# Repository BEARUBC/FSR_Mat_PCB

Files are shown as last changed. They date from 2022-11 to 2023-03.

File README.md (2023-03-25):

# FSR Matrix Printed Circuit Board

**As of 2023-03-24, this README is outdated. Documentation for Tiaan's FSR is in progress. 

<p align="center">
These are the CAD files for the FSR printed circuit boards (PCB) using through-hole only components. This board is used for controlling a force sensitive resistor matrix, reading analog values from each cell.  
</p>

## 📖 Description

This design is based off of Sensitronics' MatrixArray products which are comprised of a multitude of force sensing resistor elements arranged in a grid.
Providing n-input multitouch + force sensing capabilities, MatrixArrays are the basis for musical instruments, PC input devices, and other innovative designs.
If you have measured single-element FSRs by looking at the voltage across a divider, we're doing the same thing here.

But in this case, we're choosing the point to measure by powering a single drive column, enabling one mux channel so that the ADC sees a single row.
In the next section, the Arduino code demonstrates a scan pattern to read all $\approx$ 160 elements in sequence.

### 🚨 Dependencies

* Software
  * KiCAD v6
* Hardware
  * ThruMode MatrixArray
  * Arduino Uno (or other)
  * 74HC595 Shift Register (x2)
  * 74HC4051 Analog Multiplexer (x2)
  * 20k resistor (x1)
  * Solderless Breadboard & Jumper Wire

### 💻 Installing

#### 🕹️ Software

Use a web browser to navigate to www.kicad.org the KiCad EDA website. Click the DOWNLOAD button on the KiCad home page. On the download page that opens, click the Windows button. Under Stable Release, click either Windows 64-bit or Windows 32-bit, depending on if you are going to install KiCad on a 32-bit or 64-bit version of the Windows operating system. Save the KiCad installation file. It may take a while to download, depending on your internet speed.

1. Click the Open button under File > Open (`Ctrl + O`) and navigate to this repository
2. Select the `force_sens_resistor.kicad_pro` file
3. Double click the `*.sch` file and begin to edit the board

#### 🤖 Hardware

Arrange the hardware connections folling this schematic:

<p align="center">
  
</p>

### ▶️ Executing program

Now that the hardware's connected, it's time to write some code.

To read a single intersection, or "cell", of the MatrixArray, we need to perform the following sequence:

* Drive the cell's row with +5V
* Enable the cell's column (multiplexer channel)
* Take an ADC reading on pin A0
* Output the reading via serial port

Simple enough, so from here, we will write a scan pattern to efficiently drive and read each cell of the Matrix. Recalling that we're calling shift register drive pins "rows" and multiplexed read pins "columns" in this example, we'll enable each column in order, and while each column is active, we'll drive each row high and take a reading.

```cpp
// Constant definitions
...

void setup() {
  Serial.begin(BAUD_RATE);

  pinMode(PIN_ADC_INPUT, INPUT);
  pinMode(PIN_SHIFT_REGISTER_DATA, OUTPUT);
  pinMode(PIN_SHIFT_REGISTER_CLOCK, OUTPUT);
  pinMode(PIN_MUX_CHANNEL_0, OUTPUT);
  pinMode(PIN_MUX_CHANNEL_1, OUTPUT);
  pinMode(PIN_MUX_CHANNEL_2, OUTPUT);
  pinMode(PIN_MUX_INHIBIT_0, OUTPUT);
  pinMode(PIN_MUX_INHIBIT_1, OUTPUT);
}
void loop() {
  for(int i = 0; i < ROW_COUNT; i ++) {
    setRow(i);
    shiftColumn(true);
    shiftColumn(false);                         //with SR clks tied, latched outputs are one clock behind

    for(int j = 0; j < COLUMN_COUNT; j ++) {
      int raw_reading = analogRead(PIN_ADC_INPUT);
      byte send_reading = (byte) (lowByte(raw_reading >> 2));
      shiftColumn(false);
      printFixed(send_reading);
      Serial.print(" ");
    }
    Serial.println();
  }
  Serial.println();
  delay(200);
}

...

// Function implementations for `setRow`, `shiftCoumn`, and `printFixed`

```

## 🧔🏽‍♂️Authors

Contributors names and contact info

Tiaan Boshoff
Kyle Kochi
Tiffany Prayitino
Umar Ali  

## 🧾 Version History

* 1.0
    * Initial Release following Sensitronics' MatrixArray tutorial

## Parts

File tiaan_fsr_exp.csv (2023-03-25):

Id | Designator | Footprint | Quantity | Designation | Supplier and ref
1 | C4,C2,C3,C1 | CP_Radial_D4.0mm_P2.00mm | 4 | 0.1uF
2 | J3,J5 | PinHeader_1x02_P2.54mm_Vertical | 2 | Conn_01x02
3 | R1 | R_Axial_DIN0207_L6.3mm_D2.5mm_P10.16mm_Horizontal | 1 | 20k
4 | J2 | JST_XH_S3B-XH-A-1_1x03_P2.50mm_Horizontal | 1 | Conn_01x03
5 | H1,H3,H4,H2 | MountingHole_2.7mm_M2.5_DIN965_Pad | 4 | MountingHole
6 | J4 | IDC-Header_2x17_P2.54mm_Vertical | 1 | Conn_02x17_Odd_Even
7 | MUX1,MUX2 | DIP-16_W7.62mm_Socket | 2 | 74HC4051
8 | SR2,SR1 | DIP-16_W7.62mm_Socket | 2 | 74HC595
9 | J1 | JST_XH_S6B-XH-A-1_1x06_P2.50mm_Horizontal | 1 | Conn_01x06

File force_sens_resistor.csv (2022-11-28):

Source: | C:\Users\umaru\Documents\cad\fsr\force_sens_resistor\force_sens_resistor.kicad_sch
Date: | 11/27/2022 8:21:04 PM
Tool: | Eeschema (6.0.6)
Generator: | C:\Program Files\KiCad\6.0\bin\scripting\plugins/bom_csv_grouped_by_value.py
Component Count: | 12
Individual Components:
Item | Qty | Reference(s) | Value | LibPart | Footprint | Datasheet
 |  | C1 | 0.1uF | Device:C_Polarized_Small_US | Capacitor_THT:CP_Axial_L10.0mm_D4.5mm_P15.00mm_Horizontal | ~
 |  | C2 | 0.1uF | Device:C_Polarized_Small_US | Capacitor_THT:CP_Axial_L10.0mm_D4.5mm_P15.00mm_Horizontal | ~
 |  | C3 | 0.1uF | Device:C_Polarized_Small_US | Capacitor_THT:CP_Axial_L10.0mm_D4.5mm_P15.00mm_Horizontal | ~
 |  | C4 | 0.1uF | Device:C_Polarized_Small_US | Capacitor_THT:CP_Axial_L10.0mm_D4.5mm_P15.00mm_Horizontal | ~
 |  | J1 | MCU_HEADER_PINS | Connector:Conn_01x09_Female | Connector_PinSocket_1.00mm:PinSocket_1x09_P1.00mm_Vertical | ~
 |  | J2 | DRIVE_COLS | Connector:Conn_01x16_Female | Connector_PinSocket_1.00mm:PinSocket_1x16_P1.00mm_Vertical | ~
 |  | J3 | READ_ROWS | Connector:Conn_01x10_Female | Connector_PinSocket_1.00mm:PinSocket_1x10_P1.00mm_Vertical | ~
 |  | R1 | 20k | Device:R_Small | Resistor_THT:R_Axial_DIN0204_L3.6mm_D1.6mm_P1.90mm_Vertical | ~
 |  | U1 | 74HCT595 | 74xx:74HCT595 | Package_DIP:DIP-16_W7.62mm_LongPads | https://assets.nexperia.com/documents/data-sheet/74HC_HCT595.pdf
 |  | U2 | 74HCT595 | 74xx:74HCT595 | Package_DIP:DIP-16_W7.62mm_LongPads | https://assets.nexperia.com/documents/data-sheet/74HC_HCT595.pdf
 |  | U3 | 4051 | 4xxx:4051 | Package_DIP:DIP-16_W10.16mm | http://www.intersil.com/content/dam/Intersil/documents/cd40/cd4051bms-52bms-53bms.pdf
 |  | U4 | 4051 | 4xxx:4051 | Package_DIP:DIP-16_W10.16mm | http://www.intersil.com/content/dam/Intersil/documents/cd40/cd4051bms-52bms-53bms.pdf
Collated Components:
Item | Qty | Reference(s) | Value | LibPart | Footprint | Datasheet
1 | 4 | C1, C2, C3, C4 | 0.1uF | Device:C_Polarized_Small_US | Capacitor_THT:CP_Axial_L10.0mm_D4.5mm_P15.00mm_Horizontal | ~
2 | 1 | J1 | MCU_HEADER_PINS | Connector:Conn_01x09_Female | Connector_PinSocket_1.00mm:PinSocket_1x09_P1.00mm_Vertical | ~
3 | 1 | J2 | DRIVE_COLS | Connector:Conn_01x16_Female | Connector_PinSocket_1.00mm:PinSocket_1x16_P1.00mm_Vertical | ~
4 | 1 | J3 | READ_ROWS | Connector:Conn_01x10_Female | Connector_PinSocket_1.00mm:PinSocket_1x10_P1.00mm_Vertical | ~
5 | 1 | R1 | 20k | Device:R_Small | Resistor_THT:R_Axial_DIN0204_L3.6mm_D1.6mm_P1.90mm_Vertical | ~
6 | 2 | U1, U2 | 74HCT595 | 74xx:74HCT595 | Package_DIP:DIP-16_W7.62mm_LongPads | https://assets.nexperia.com/documents/data-sheet/74HC_HCT595.pdf
7 | 2 | U3, U4 | 4051 | 4xxx:4051 | Package_DIP:DIP-16_W10.16mm | http://www.intersil.com/content/dam/Intersil/documents/cd40/cd4051bms-52bms-53bms.pdf

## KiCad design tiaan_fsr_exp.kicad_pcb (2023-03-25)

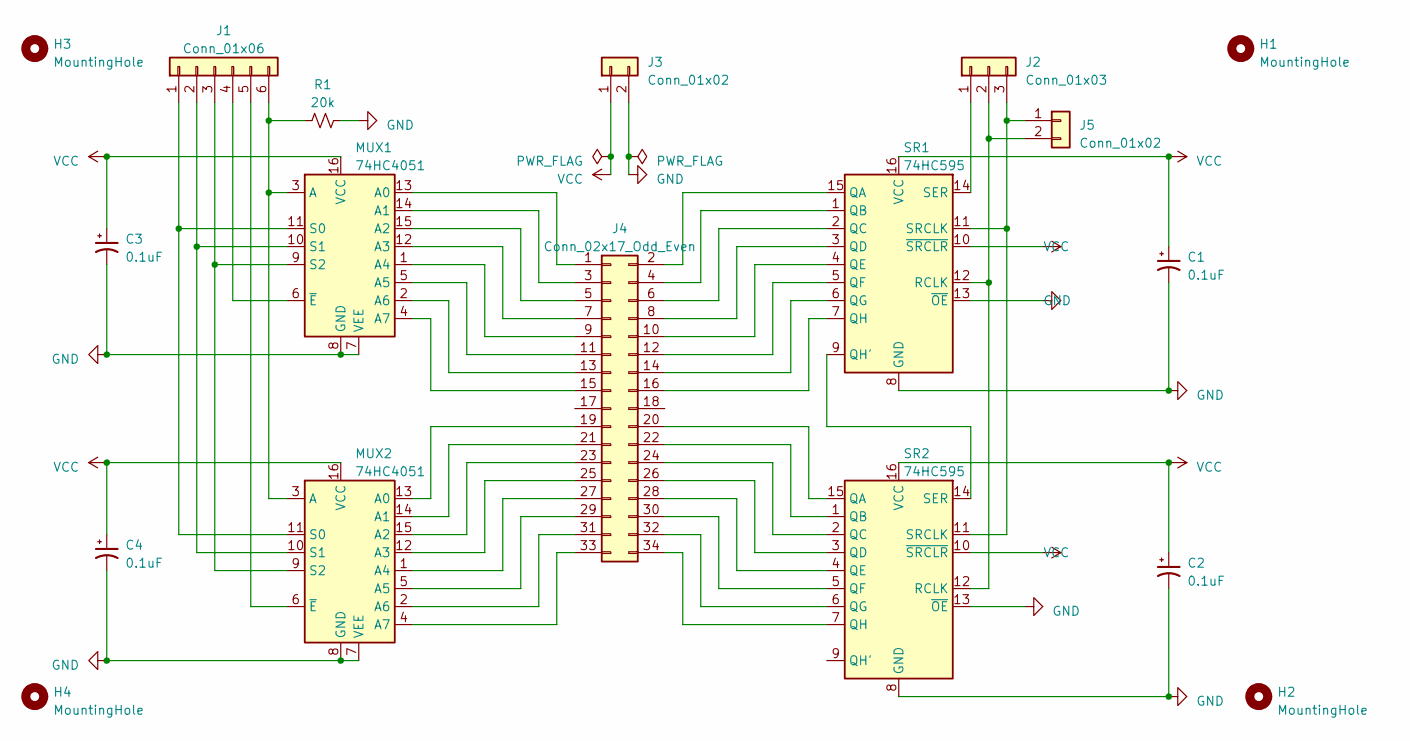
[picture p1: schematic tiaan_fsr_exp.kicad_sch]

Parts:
C1, C2, C3, C4: 0.1uF; CP_Radial_D4.0mm_P2.00mm
H1, H2, H3, H4: MountingHole; MountingHole_2.7mm_M2.5_DIN965_Pad
J1: Conn_01x06; JST_XH_S6B-XH-A-1_1x06_P2.50mm_Horizontal
J2: Conn_01x03; JST_XH_S3B-XH-A-1_1x03_P2.50mm_Horizontal
J3, J5: Conn_01x02; PinHeader_1x02_P2.54mm_Vertical
J4: Conn_02x17_Odd_Even; IDC-Header_2x17_P2.54mm_Vertical
MUX1, MUX2: 74HC4051; DIP-16_W7.62mm_Socket
R1: 20k; R_Axial_DIN0207_L6.3mm_D2.5mm_P10.16mm_Horizontal
SR1, SR2: 74HC595; DIP-16_W7.62mm_Socket

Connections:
GND: C1.2, C2.2, C3.2, C4.2, J3.2, MUX1.7 (VEE), MUX1.8 (GND), MUX2.7 (VEE), MUX2.8 (GND), R1.2, SR1.8 (GND), SR1.13 (~OE), SR2.8 (GND), SR2.13 (~OE)
unnamed: J1.1, MUX1.11 (S0), MUX2.11 (S0)
unnamed: J1.2, MUX1.10 (S1), MUX2.10 (S1)
unnamed: J1.3, MUX1.9 (S2), MUX2.9 (S2)
unnamed: J1.4, MUX1.6 (~E)
unnamed: J1.5, MUX2.6 (~E)
unnamed: J1.6, MUX1.3 (A), MUX2.3 (A), R1.1
unnamed: J2.1, SR1.14 (SER)
unnamed: J2.2, J5.2, SR1.12 (RCLK), SR2.12 (RCLK)
unnamed: J2.3, J5.1, SR1.11 (SRCLK), SR2.11 (SRCLK)
unnamed: J4.1, MUX1.13 (A0)
unnamed: J4.2, SR1.15 (QA)
unnamed: J4.3, MUX1.14 (A1)
unnamed: J4.4, SR1.1 (QB)
unnamed: J4.5, MUX1.15 (A2)
unnamed: J4.6, SR1.2 (QC)
unnamed: J4.7, MUX1.12 (A3)
unnamed: J4.8, SR1.3 (QD)
unnamed: J4.9, MUX1.1 (A4)
unnamed: J4.10, SR1.4 (QE)
unnamed: J4.11, MUX1.5 (A5)
unnamed: J4.12, SR1.5 (QF)
unnamed: J4.13, MUX1.2 (A6)
unnamed: J4.14, SR1.6 (QG)
unnamed: J4.15, MUX1.4 (A7)
unnamed: J4.16, SR1.7 (QH)
unnamed: J4.19, MUX2.13 (A0)
unnamed: J4.20, SR2.15 (QA)
unnamed: J4.21, MUX2.14 (A1)
unnamed: J4.22, SR2.1 (QB)
unnamed: J4.23, MUX2.15 (A2)
unnamed: J4.24, SR2.2 (QC)
unnamed: J4.25, MUX2.12 (A3)
unnamed: J4.26, SR2.3 (QD)
unnamed: J4.27, MUX2.1 (A4)
unnamed: J4.28, SR2.4 (QE)
unnamed: J4.29, MUX2.5 (A5)
unnamed: J4.30, SR2.5 (QF)
unnamed: J4.31, MUX2.2 (A6)
unnamed: J4.32, SR2.6 (QG)
unnamed: J4.33, MUX2.4 (A7)
unnamed: J4.34, SR2.7 (QH)
unnamed: SR1.9 (QH'), SR2.14 (SER)
VCC: C1.1, C2.1, C3.1, C4.1, J3.1, MUX1.16 (VCC), MUX2.16 (VCC), SR1.10 (~SRCLR), SR1.16 (VCC), SR2.10 (~SRCLR), SR2.16 (VCC)

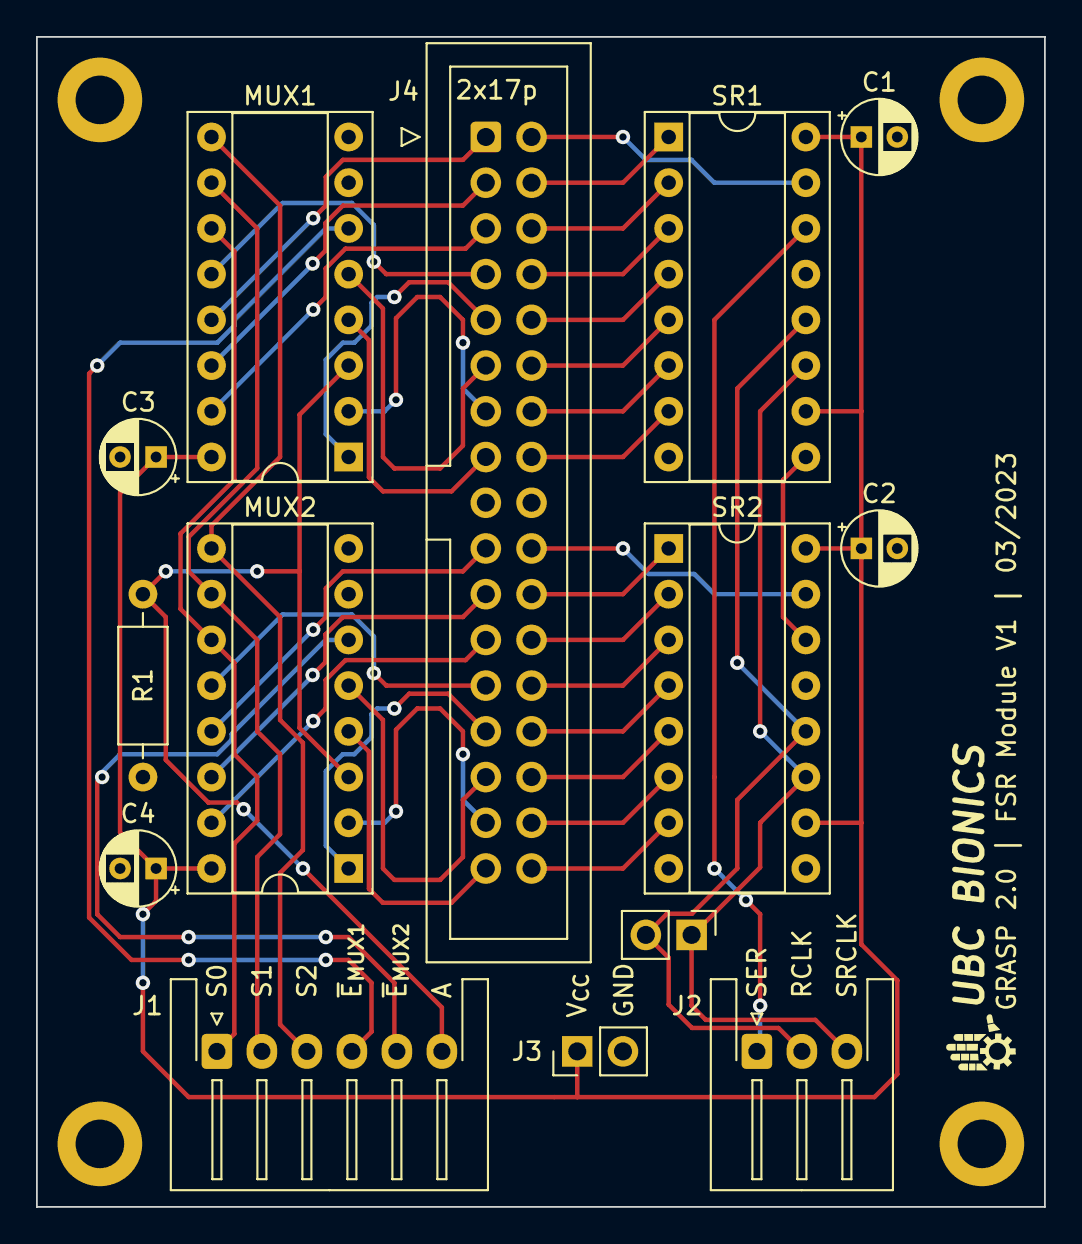
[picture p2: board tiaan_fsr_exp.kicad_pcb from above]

Board: 2 copper layers, 56.0 x 65.0 mm, 18 parts (0 on the bottom side), 44 nets.

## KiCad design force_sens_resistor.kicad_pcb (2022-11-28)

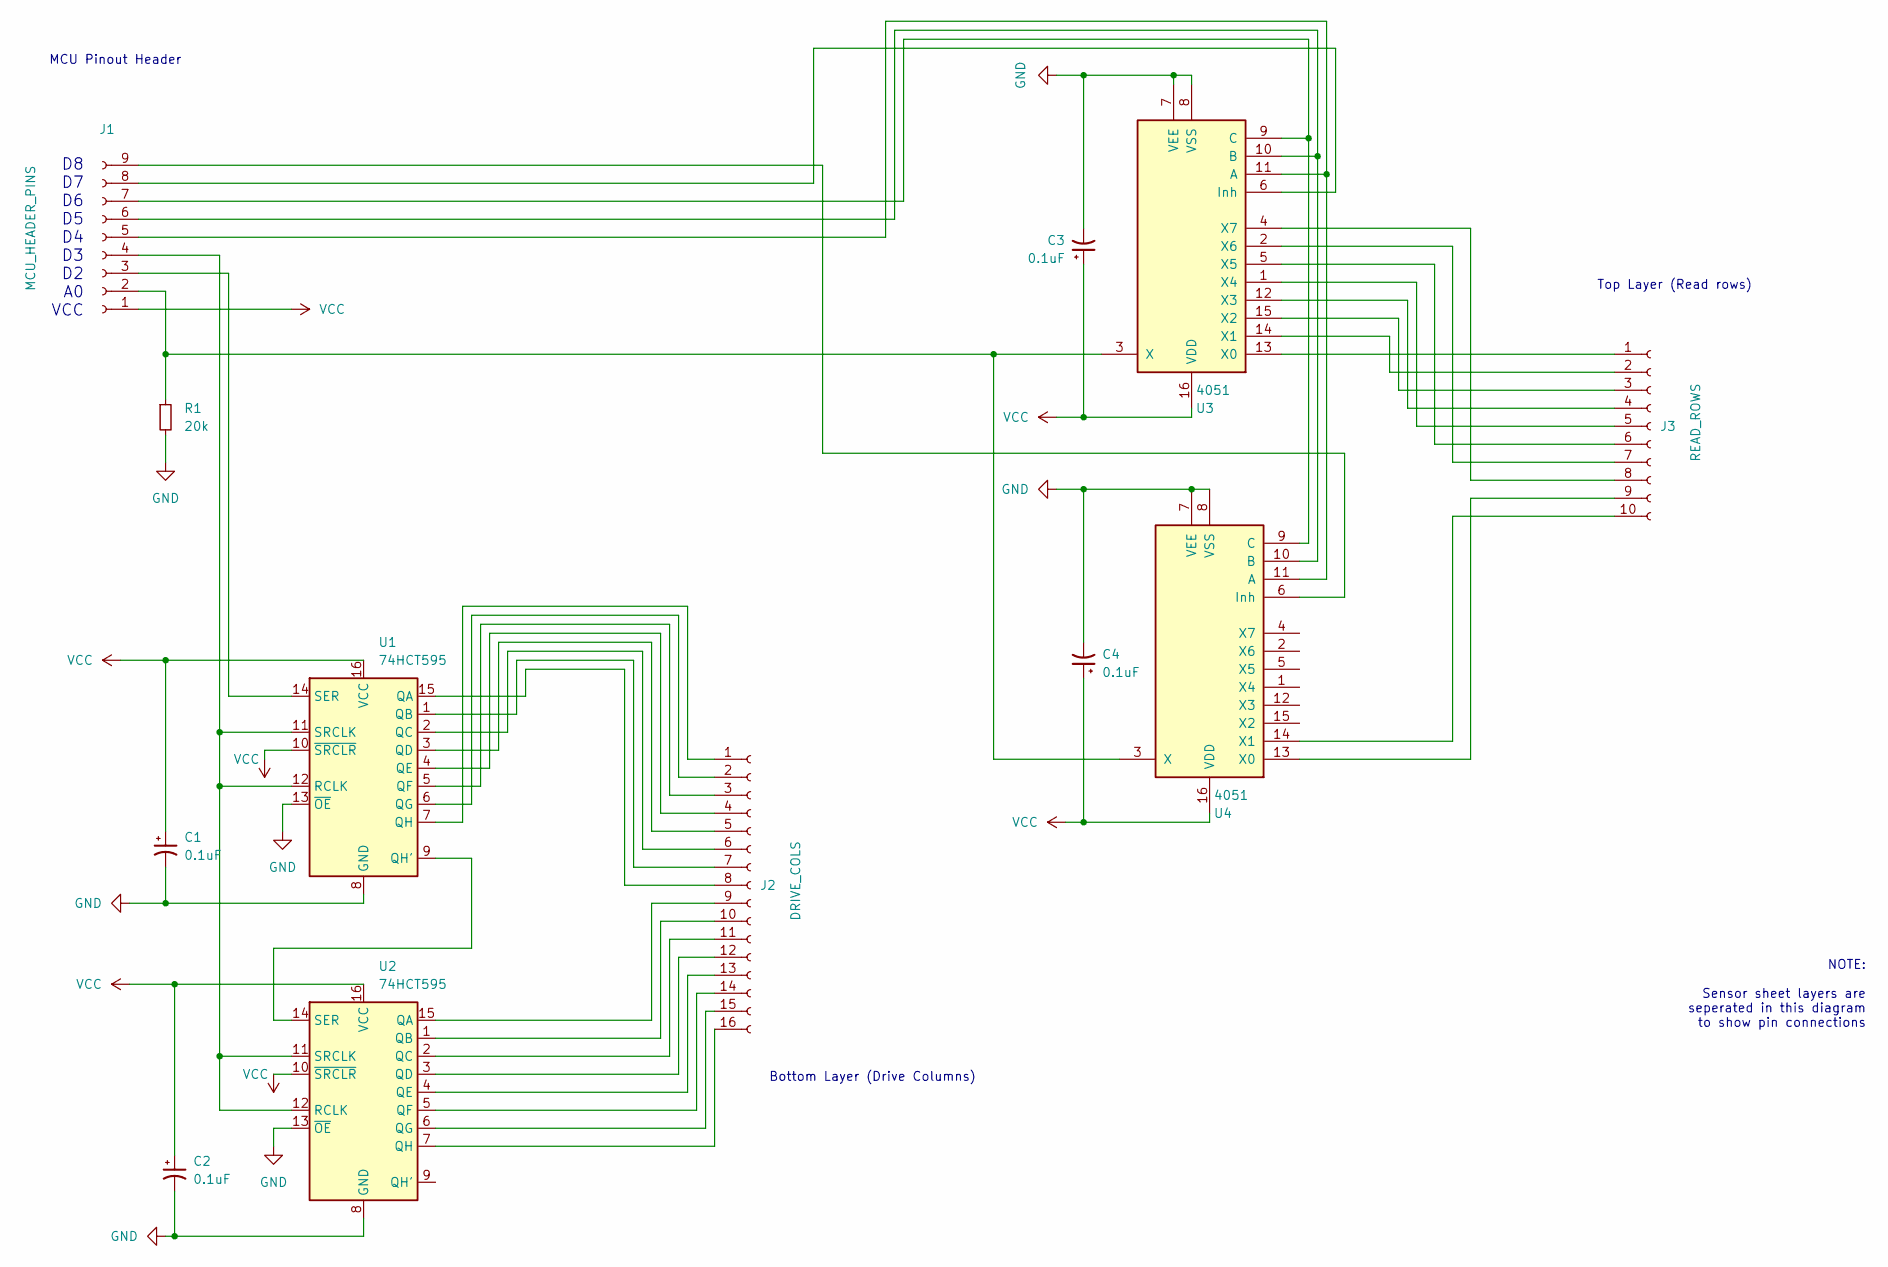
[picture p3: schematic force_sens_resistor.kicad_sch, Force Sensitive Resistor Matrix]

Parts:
C1, C2, C3, C4: 0.1uF; CP_Axial_L10.0mm_D4.5mm_P15.00mm_Horizontal
J1: MCU_HEADER_PINS; PinSocket_1x09_P1.00mm_Vertical
J2: DRIVE_COLS; PinSocket_1x16_P1.00mm_Vertical
J3: READ_ROWS; PinSocket_1x10_P1.00mm_Vertical
R1: 20k; R_Axial_DIN0204_L3.6mm_D1.6mm_P1.90mm_Vertical
U1, U2: 74HCT595; DIP-16_W7.62mm_LongPads
U3, U4: 4051; DIP-16_W10.16mm

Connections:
GND: C1.2, C2.2, C3.2, C4.2, R1.2, U1.8 (GND), U1.13 (~OE), U2.8 (GND), U2.13 (~OE), U3.7 (VEE), U3.8 (VSS), U4.7 (VEE), U4.8 (VSS)
unnamed: J1.2, R1.1, U3.3 (X), U4.3 (X)
unnamed: J1.3, U1.14 (SER)
unnamed: J1.4, U1.11 (SRCLK), U1.12 (RCLK), U2.11 (SRCLK), U2.12 (RCLK)
unnamed: J1.5, U3.11 (A), U4.11 (A)
unnamed: J1.6, U3.10 (B), U4.10 (B)
unnamed: J1.7, U3.9 (C), U4.9 (C)
unnamed: J1.8, U3.6 (Inh)
unnamed: J1.9, U4.6 (Inh)
unnamed: J2.1, U1.7 (QH)
unnamed: J2.2, U1.6 (QG)
unnamed: J2.3, U1.5 (QF)
unnamed: J2.4, U1.4 (QE)
unnamed: J2.5, U1.3 (QD)
unnamed: J2.6, U1.2 (QC)
unnamed: J2.7, U1.1 (QB)
unnamed: J2.8, U1.15 (QA)
unnamed: J2.9, U2.15 (QA)
unnamed: J2.10, U2.1 (QB)
unnamed: J2.11, U2.2 (QC)
unnamed: J2.12, U2.3 (QD)
unnamed: J2.13, U2.4 (QE)
unnamed: J2.14, U2.5 (QF)
unnamed: J2.15, U2.6 (QG)
unnamed: J2.16, U2.7 (QH)
unnamed: J3.1, U3.13 (X0)
unnamed: J3.2, U3.14 (X1)
unnamed: J3.3, U3.15 (X2)
unnamed: J3.4, U3.12 (X3)
unnamed: J3.5, U3.1 (X4)
unnamed: J3.6, U3.5 (X5)
unnamed: J3.7, U3.2 (X6)
unnamed: J3.8, U3.4 (X7)
unnamed: J3.9, U4.13 (X0)
unnamed: J3.10, U4.14 (X1)
unnamed: U1.9 (QH'), U2.14 (SER)
VCC: C1.1, C2.1, C3.1, C4.1, J1.1, U1.10 (~SRCLR), U1.16 (VCC), U2.10 (~SRCLR), U2.16 (VCC), U3.16 (VDD), U4.16 (VDD)

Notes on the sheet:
D8 D7 D6 D5 D4 D3 D2 A0 VCC
Bottom Layer (Drive Columns)
MCU Pinout Header
NOTE: Sensor sheet layers are seperated in this diagram to show pin connections
Top Layer (Read rows)

Board: 2 copper layers, 12 parts (0 on the bottom side), 37 nets, no tracks yet.

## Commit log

2022-11-28 Add initial CAD files for FSR
    [force_sens_resistor.csv, force_sens_resistor.kicad_pcb, force_sens_resistor.kicad_sch]
2023-03-25 Added Tiaan's FSR v1
    [tiaan_fsr_exp-B_Cu.gbr, tiaan_fsr_exp-B_Mask.gbr, tiaan_fsr_exp-B_Paste.gbr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]
